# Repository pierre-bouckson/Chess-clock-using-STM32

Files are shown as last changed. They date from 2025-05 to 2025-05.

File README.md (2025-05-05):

# Chess Clock using STM32

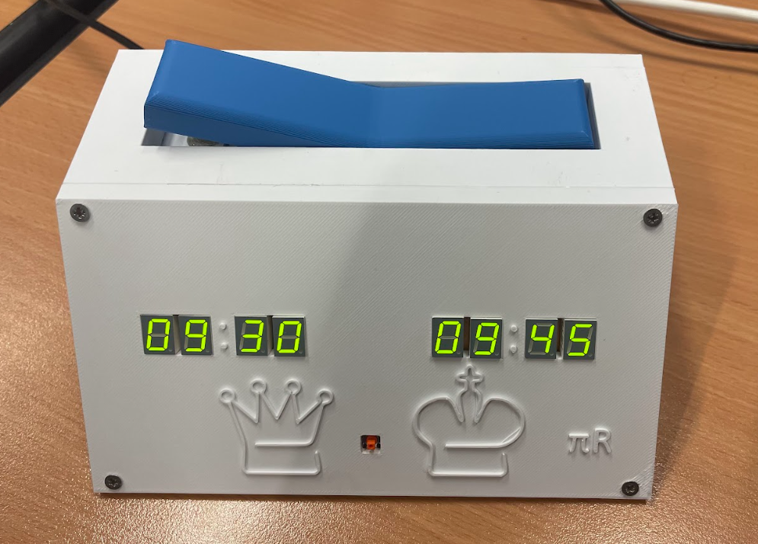
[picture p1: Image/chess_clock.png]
Chess Clock Overview


A fully functional chess clock built with an STM32 microcontroller, using hardware timers and external components for a realistic, competitive experience. This project combines embedded programming, electronics, and 3D printing.

---

## Required Equipment

1. **STM32F072RB** microcontroller (or any STM32 with hardware timers)
2. **3D-printed enclosure**
3. **5V power supply** (via USB power bank)
4. **4 screws** (for enclosure assembly)
5. **Shaft** – 3.5mm diameter, 6cm long
6. **4 magnets**
7. **8-digit 7-segment display**  
   [TDSG3160-M – Vishay](https://fr.farnell.com/vishay/tdsg3160-m/7-seg-display-com-cathode-grn/dp/3777869)
8. **2 LED display drivers**  
   [MAX6958AAEE – Analog Devices](https://fr.farnell.com/analog-devices/max6958aaee/driver-afficheur-led-40-a-125/dp/2516031)
9. **Passive components**: resistors, capacitors, tactile button, etc.

---

## Tools Used

- [KiCad](https://kicad.org/) – for PCB design
- [STM32CubeIDE](https://www.st.com/en/development-tools/stm32cubeide.html) – for firmware development

---

## Project Overview

The chess clock is powered by an **STM32F072RB**, using two hardware timers (TIM6 and TIM7) to track each player's countdown in real time. Turn switching is handled by a physical mechanism using a rotating shaft and magnets. Two **MAX6958** drivers control the 7-segment displays. The clock supports multiple time modes and optional time increments.

---

## Assembly Guide

### 1. Print the Enclosure

- Insert magnets into the 4 dedicated holes.
- Create a custom push-button using aluminum (as shown below):

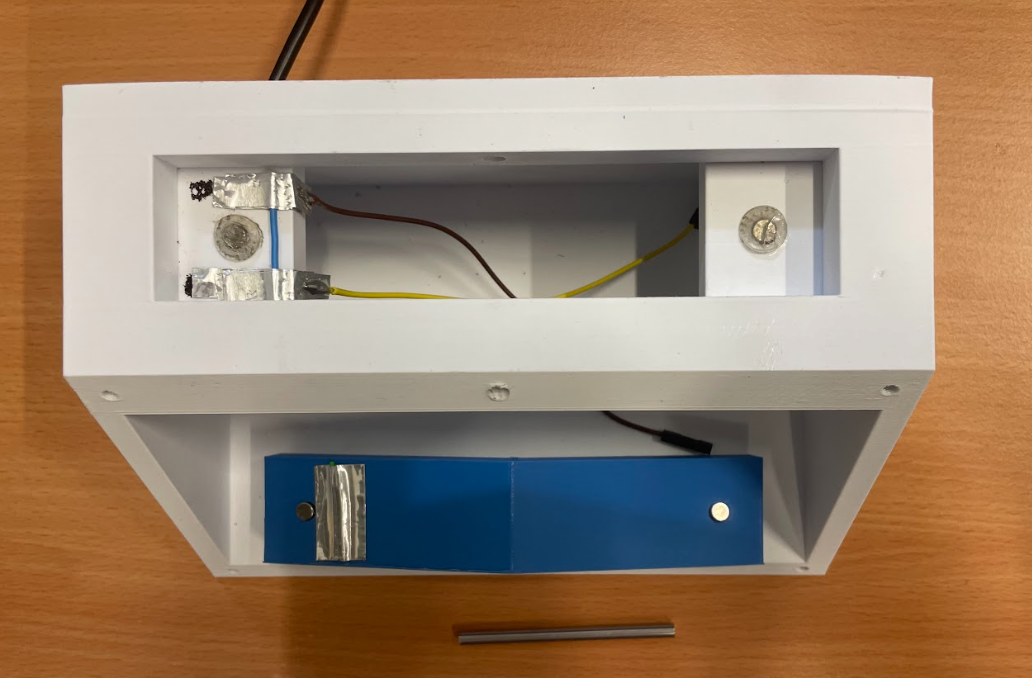
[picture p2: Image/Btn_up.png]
Button Example
  

- Connect the button between **5V** and **PB0**.
- Drill a hole in the enclosure to pass the power cable.

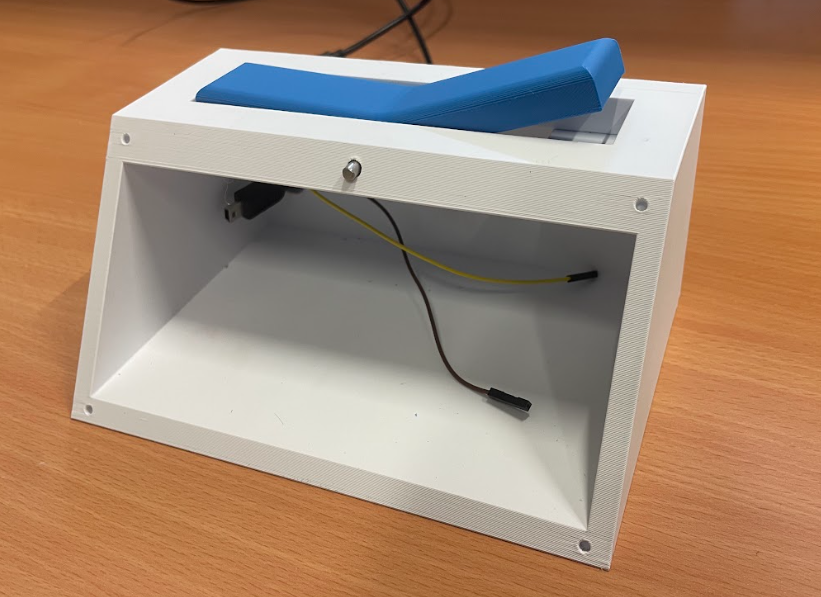
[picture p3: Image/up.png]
Wiring Example
  

### 2. Prepare the Electronics

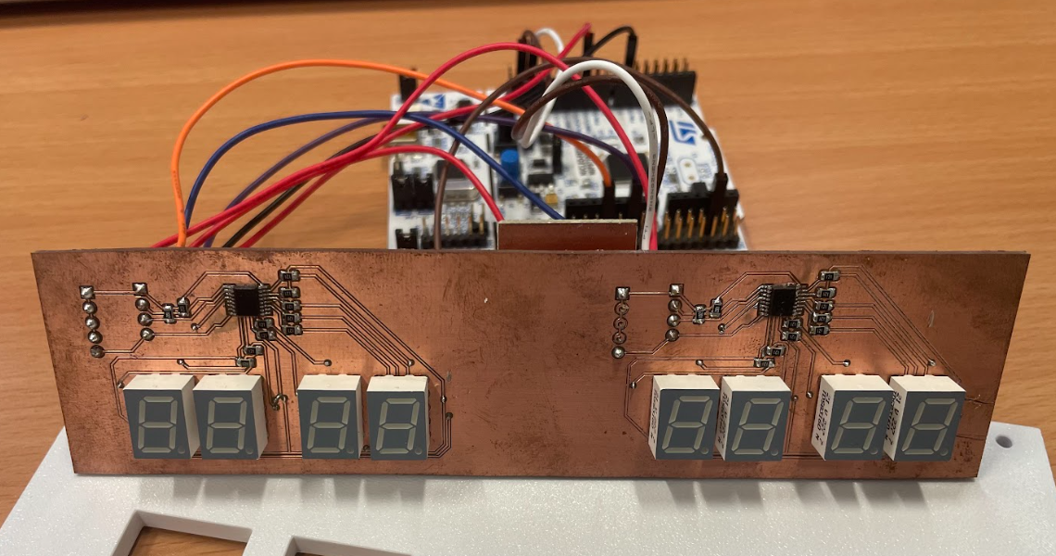
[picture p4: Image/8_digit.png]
Display Wiring
  

- Use **4 pull-up resistors** (1kΩ) for I2C communication.
- Use **9 resistors** (330Ω) for the LED segments.
- Connect the first display driver to:  
  - 3.3V, GND  
  - PB8 (SCL), PB9 (SDA)

- Connect the second driver to:  
  - 3.3V, GND  
  - PB10 (SCL), PB11 (SDA)

> Don't forget to add **decoupling capacitors** near the power pins.

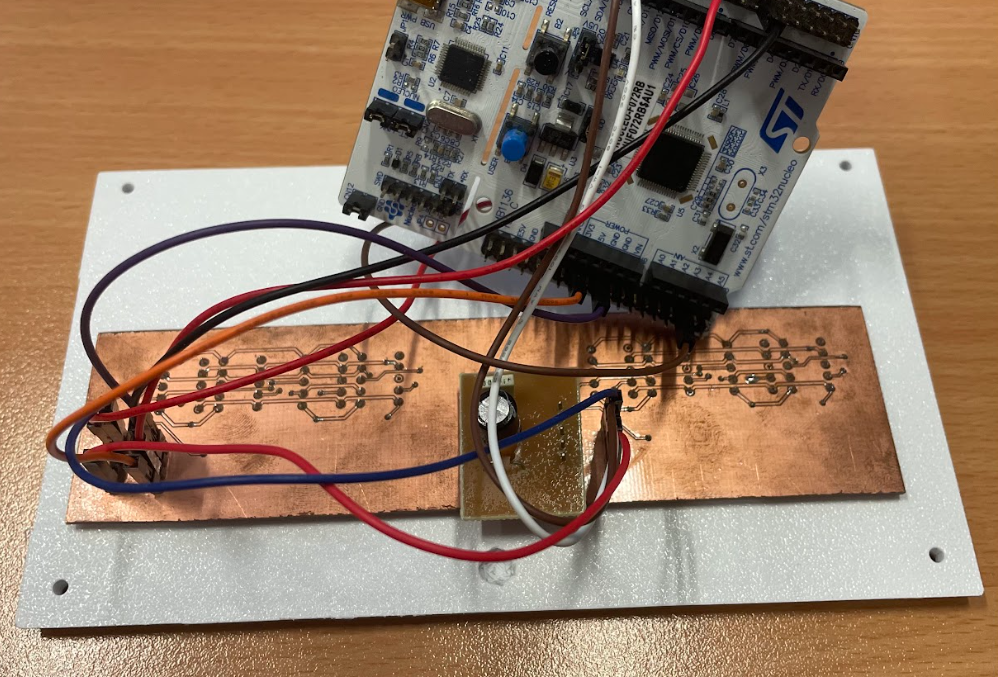
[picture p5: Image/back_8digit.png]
Back View
  

---

## Repository Structure

- `3D_model/` – 3D-printable enclosure files (STL)
- `software_STM32/` – STM32 firmware (C)
- `Image/` – Photos
- `hardware_kicad/` – Schematics and PCB files
- `README.md` – This file

---

Feel free to clone the repository, give feedback, or open issues!

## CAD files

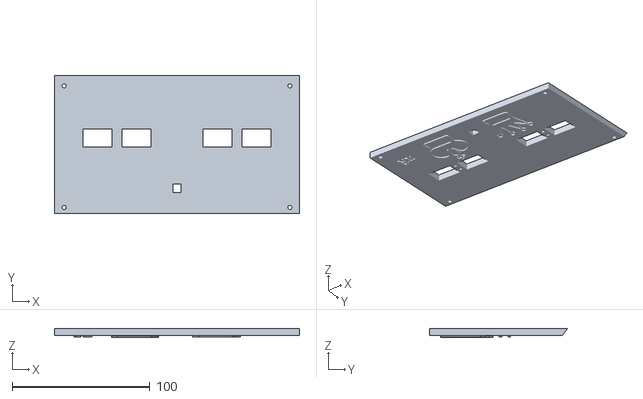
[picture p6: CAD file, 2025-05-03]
3D_model/STL/Assemblagev4-fin.STL
177.6 x 100.0 x 6.18

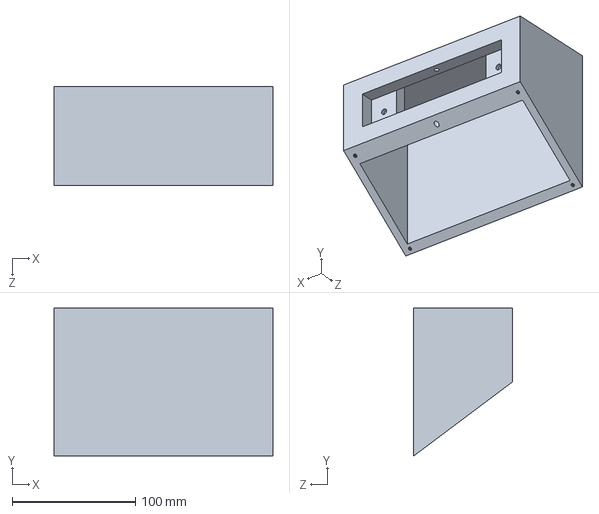
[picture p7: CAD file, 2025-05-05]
3D_model/SolidWorks/boite.SLDPRT
177.6 x 120.0 x 80.0 mm

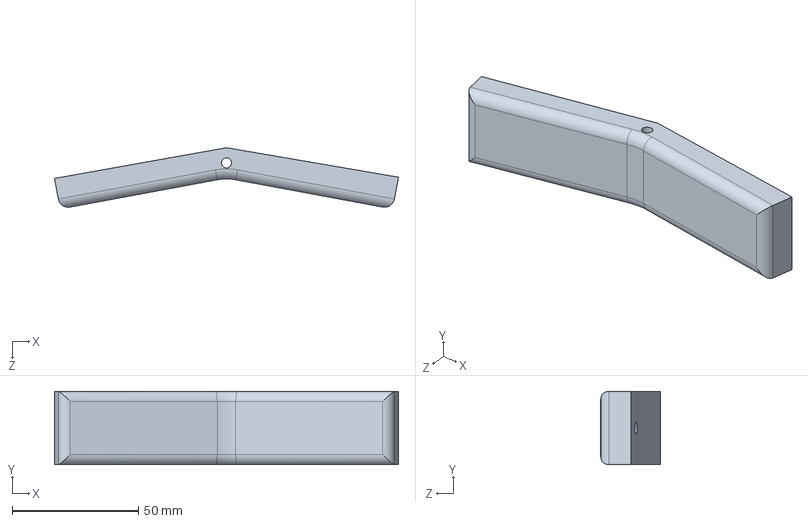
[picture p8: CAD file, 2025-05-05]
3D_model/SolidWorks/bouton.SLDPRT
136.1 x 29.0 x 23.5 mm

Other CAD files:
3D_model/STL/boite_2.0.STL
3D_model/SolidWorks/face.SLDPRT
3D_model/STL/bouton2.0.STL
3D_model/STL/bouton.STL

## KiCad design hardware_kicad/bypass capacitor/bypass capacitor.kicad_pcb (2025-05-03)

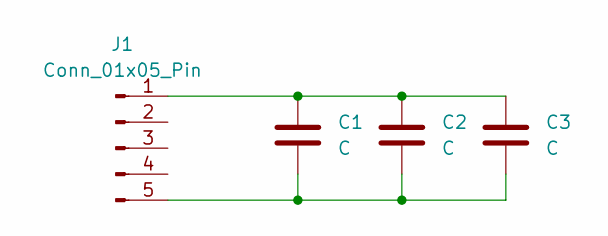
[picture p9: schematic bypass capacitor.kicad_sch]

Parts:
C1: C; C_Disc_D5.1mm_W3.2mm_P5.00mm
C2: C; C_Rect_L9.0mm_W2.5mm_P7.50mm_MKT
C3: C; CP_Radial_D8.0mm_P3.50mm
J1: Conn_01x05_Pin; PinHeader_1x05_P2.54mm_Vertical

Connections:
unnamed: C1.1, C2.1, C3.1, J1.1
unnamed: C1.2, C2.2, C3.2, J1.5

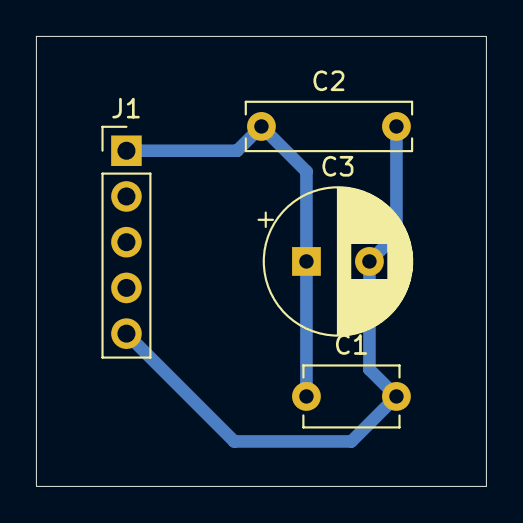
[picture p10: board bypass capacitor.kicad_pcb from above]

Board: 2 copper layers, 25.0 x 25.0 mm, 4 parts (0 on the bottom side), 2 nets.

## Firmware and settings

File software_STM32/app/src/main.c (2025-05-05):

/*
 * main.c
 *
 *  Created on: 5 août 2017
 *      Author: Pierre
 */


 #include "stm32f0xx.h"
 #include "bsp.h"
 #include "delay.h"
 #include "main.h"
 #include "sinewave_table.h"
 #include "rtc.h"
 
 #define N 60000
 
 // Static functions
 static void SystemClock_Config(void);
 void temps_bonus(uint8_t joueur);
 
 
 uint16_t	TIM6_counter;
 uint16_t	TIM7_counter;
 
 uint8_t min_passe_TIM6 = 0;
 uint8_t min_passe_TIM7 = 0;
 
 uint8_t min_TIM6;
 uint8_t min_TIM7;
 
 uint8_t etat = 1;
 uint8_t etat_btn;
 uint8_t temps = 1;
 uint8_t button_irq = 0;
 uint8_t button_irqPA4;
 uint8_t button_irqPC3;
 uint8_t choose = 1;
 
 uint32_t temps_bonus1 = 0;
 uint32_t temps_bonus2 = 0;
 
 
 uint32_t    Temps_a_jouer; //   <-----------  Temps des joueurs
 
 
 // Main function
 int main()
 {
	 // Configure System Clock
	 SystemClock_Config();
 
	 BSP_PB_Init();
	 BSP_PBPA4_Init();
 
	 BSP_TIMER6_Timebase_Init();  //Timer6
	 BSP_TIMER7_Timebase_Init();  //Timer7
 
	 BSP_I2C1_Init1();
	 BSP_I2C1_Init2();
 
	 MAX6958_Init1();  //Driver LED 1
	 MAX6958_Init2();  //Driver LED 2
 
	 BSP_NVIC_Init();
 
	 // Main loop
	 while(1)
	 {
 
		 if (button_irq >= 1)
		 {
			 if(temps == 5)
			 {
				 temps=1;
			 }
			 else
			 {
				 temps++;
			 }
 
			 TIM6->EGR |= TIM_EGR_UG;
			 TIM7->EGR |= TIM_EGR_UG;
			 TIM6->CR1 &= ~TIM_CR1_CEN;
			 TIM7->CR1 &= ~TIM_CR1_CEN;
 
			 etat = 1;
			 choose = 1;
 
			 min_passe_TIM6 = 0;
			 min_passe_TIM7 = 0;
			 min_TIM6 = 0;
			 min_TIM7 = 0;
			 temps_bonus1=0;
			 temps_bonus2=0;
 
			 MAX6958_Init1();
			 MAX6958_Init2();
 
			 button_irq = 0;
 
			 etat_btn = BSP_PBPA4_GetState();
		 }
 
 
		 switch(temps)
		 {
		 case 1:
			 Temps_a_jouer = 60000;
			 break;
		 case 2 :
			 Temps_a_jouer = 180000;
			 break;
		 case 3 :
			 Temps_a_jouer = 180000;
			 break;
		 case 4 :
			 Temps_a_jouer = 300000;
			 break;
		 case 5 :
			 Temps_a_jouer = 600000;
			 break;
		 }
 
 
		 switch(etat)
		 {
		 case 1 :  //		Etat de debut, aucune clock lancer
			 if(BSP_PBPA4_GetState() != etat_btn){
				 choose = 0;
				 if(BSP_PBPA4_GetState() == 0)
				 {
					 etat = 3;
				 }
				 if(BSP_PBPA4_GetState() == 1)
				 {
					 etat = 2;
				 }
			 }
			 break;
 
		 case 2 :
 
			 TIM6->CR1 &= ~TIM_CR1_CEN;//		Pause TIM6
			 TIM7->CR1 |= TIM_CR1_CEN;//         TIM7 lancer
			 if(BSP_PBPA4_GetState() == 0)
			 {
				 etat = 3;
				 temps_bonus(1);
			 }
			 break;
 
		 case 3 :
 
			 TIM7->CR1 &= ~TIM_CR1_CEN;// 		Pause TIM7
			 TIM6->CR1 |= TIM_CR1_CEN;//         TIM6 lancer
			 if(BSP_PBPA4_GetState() == 1)
			 {
				 etat = 2;
				 temps_bonus(2);
			 }
			 break;
		 }
 
		 // PRINT DIGIT
		 if(choose == 0)
		 {
			 print_digit1(Temps_a_jouer + temps_bonus1 - (min_passe_TIM7*60000) - TIM7->CNT);
			 print_digit2(Temps_a_jouer + temps_bonus2 - (min_passe_TIM6*60000) - TIM6->CNT);
		 }
		 else
		 {
			 print_digit2(Temps_a_jouer);
			 if(temps == 3)
			 {
				 print_digit1(2000);
			 }
			 else if(temps == 1)
			 {
				 print_digit1(1000);
			 }
			 else
			 {
				 print_digit1(0);
			 }
 
		 }
 
		 // AJOUT MIN
		 if(min_TIM6 == 1)
		 {
			 min_passe_TIM6++;
			 min_TIM6 = 0;
		 }
 
		 if(min_TIM7 == 1)
		 {
			 min_passe_TIM7++;
			 min_TIM7 = 0;
		 }
 
		 // SI PERDU :
		 if((Temps_a_jouer + temps_bonus1 - (min_passe_TIM6*60000) - TIM6->CNT) < 500){
			 etat = 1;				//retourne a l'etat 1
			 print_digit2(0);		//Rester a 00:00 si perdu au temps
		 }
 
		 if((Temps_a_jouer + temps_bonus2 - (min_passe_TIM7*60000) - TIM7->CNT) < 500){
			 etat = 1;
			 print_digit1(0);		//Rester a 00:00 si perdu au temps
		 }
 
	 }
 
 }
 
 void temps_bonus(uint8_t joueur)
 {
	 if(temps == 3)
	 {
		 if(joueur == 1)
		 {
			 temps_bonus1 += 2000;
		 }
		 else
		 {
			 temps_bonus2 += 2000;
		 }
	 }
	 if(temps == 1)
	 {
		 if(joueur == 1)
		 {
			 temps_bonus1 += 1000;
		 }
		 else
		 {
			 temps_bonus2 += 1000;
		 }
	 }
 }
 
 
 
 
 
 static void SystemClock_Config()
 {
	 uint32_t	HSE_Status;
	 uint32_t	PLL_Status;
	 uint32_t	SW_Status;
	 uint32_t	timeout = 0;
	 timeout = 1000000;
	 // Start HSE in Bypass Mode
	 RCC->CR |= RCC_CR_HSEBYP;
	 RCC->CR |= RCC_CR_HSEON;
	 // Wait until HSE is ready
	 do
	 {
		 HSE_Status = RCC->CR & RCC_CR_HSERDY_Msk;
		 timeout--;
	 } while ((HSE_Status == 0) && (timeout > 0));
	 // Select HSE as PLL input source
	 RCC->CFGR &= ~RCC_CFGR_PLLSRC_Msk;
	 RCC->CFGR |= (0x02 <<RCC_CFGR_PLLSRC_Pos);
	 // Set PLL PREDIV to /1
	 RCC->CFGR2 = 0x00000000;
	 // Set PLL MUL to x6
	 RCC->CFGR &= ~RCC_CFGR_PLLMUL_Msk;
	 RCC->CFGR |= (0x04 <<RCC_CFGR_PLLMUL_Pos);
	 // Enable the main PLL
	 RCC-> CR |= RCC_CR_PLLON;
	 // Wait until PLL is ready
	 do
	 {
		 PLL_Status = RCC->CR & RCC_CR_PLLRDY_Msk;
		 timeout--;
	 } while ((PLL_Status == 0) && (timeout > 0));
	 // Set AHB prescaler to /1
	 RCC->CFGR &= ~RCC_CFGR_HPRE_Msk;
	 RCC->CFGR |= RCC_CFGR_HPRE_DIV1;
	 //Set APB1 prescaler to /1
	 RCC->CFGR &= ~RCC_CFGR_PPRE_Msk;
	 RCC->CFGR |= RCC_CFGR_PPRE_DIV1;
	 // Enable FLASH Prefetch Buffer and set Flash Latency
	 FLASH->ACR = FLASH_ACR_PRFTBE | FLASH_ACR_LATENCY;
	 /* --- Until this point, MCU was still clocked by HSI at 8MHz ---*/
	 /* --- Switching to PLL at 48MHz Now!  Fasten your seat belt! ---*/
	 // Select the main PLL as system clock source
	 RCC->CFGR &= ~RCC_CFGR_SW;
	 RCC->CFGR |= RCC_CFGR_SW_PLL;
	 // Wait until PLL becomes main switch input
	 do
	 {
		 SW_Status = (RCC->CFGR & RCC_CFGR_SWS_Msk);
		 timeout--;
	 } while ((SW_Status != RCC_CFGR_SWS_PLL) && (timeout > 0));
	 /* --- Here we go! ---*/
	 /*--- Use PA8 as MCO output at 48/16 = 3MHz ---*/
	 // Set MCO source as SYSCLK (48MHz)
	 RCC->CFGR &= ~RCC_CFGR_MCO_Msk;
	 RCC->CFGR |=  RCC_CFGR_MCOSEL_SYSCLK;
	 // Set MCO prescaler to /16 -> 3MHz
	 RCC->CFGR &= ~RCC_CFGR_MCOPRE_Msk;
	 RCC->CFGR |=  RCC_CFGR_MCOPRE_DIV16;
	 // Enable GPIOA clock
	 RCC->AHBENR |= RCC_AHBENR_GPIOAEN;
	 // Configure PA8 as Alternate function
	 GPIOA->MODER &= ~GPIO_MODER_MODER8_Msk;
	 GPIOA->MODER |= (0x02 <<GPIO_MODER_MODER8_Pos);
	 // Set to AF0 (MCO output)
	 GPIOA->AFR[1] &= ~(0x0000000F);
	 GPIOA->AFR[1] |=  (0x00000000);
	 // Update SystemCoreClock global variable
	 SystemCoreClockUpdate();
 }
 

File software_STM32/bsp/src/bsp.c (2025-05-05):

/*
 * bsp.c
 *
 *  Created on: 5 août 2017
 *      Author: Laurent
 */

 #include "bsp.h"

 /*
  * BSP_PB_Init()
  * Initialize Push-Button pin (PC13) as input without Pull-up/Pull-down
  */
 
 void BSP_PB_Init()
 {
	 // Enable GPIOB clock
	 RCC->AHBENR |= RCC_AHBENR_GPIOBEN;
 
	 // Configure PB0 as input
	 GPIOB->MODER &= ~GPIO_MODER_MODER0_Msk;
	 GPIOB->MODER |= (0x00 <<GPIO_MODER_MODER0_Pos);
 
	 // Enable PB0 Pull-down
	 GPIOB->PUPDR &= ~GPIO_PUPDR_PUPDR0_Msk;
	 GPIOB->PUPDR |= (0x2UL << GPIO_PUPDR_PUPDR0_Pos);
 
	 // Enable SYSCFG clock
	 RCC->APB2ENR |= RCC_APB2ENR_SYSCFGEN;
 
	 // Select Port C as interrupt source for EXTI line 13
	 SYSCFG->EXTICR[0] &= ~ SYSCFG_EXTICR1_EXTI0_Msk;
	 SYSCFG->EXTICR[0] |=   SYSCFG_EXTICR1_EXTI0_PB;
 
	 // Enable EXTI line 0
	 EXTI->IMR |= EXTI_IMR_IM0;
 
	 // Disable Rising / Enable Falling trigger
	 EXTI->RTSR &= ~EXTI_RTSR_RT0;
	 EXTI->FTSR |=  EXTI_FTSR_FT0;
 }
 /*
  * BSP_PB_GetState()
  * Returns the state of the button (0=released, 1=pressed)
  */
 
 void BSP_PBPA4_Init()
 {
	 // Enable GPIOA clock
	 RCC->AHBENR |= RCC_AHBENR_GPIOAEN;
 
	 // Configure PA4 as input
	 GPIOA->MODER &= ~GPIO_MODER_MODER4_Msk;
	 GPIOA->MODER |= (0x00 <<GPIO_MODER_MODER4_Pos);
 
	 // Enable PA4 Pull-down
	 GPIOA->PUPDR &= ~GPIO_PUPDR_PUPDR4_Msk;
	 GPIOA->PUPDR |= (0x2UL << GPIO_PUPDR_PUPDR4_Pos);
 
	 // Enable SYSCFG clock
	 RCC->APB2ENR |= RCC_APB2ENR_SYSCFGEN;
 
	 // Select Port C as interrupt source for EXTI line 13
	 SYSCFG->EXTICR[1] &= ~ SYSCFG_EXTICR2_EXTI4_Msk;
	 SYSCFG->EXTICR[1] |=   SYSCFG_EXTICR2_EXTI4_PA;
 
	 // Enable EXTI line 4
	 EXTI->IMR |= EXTI_IMR_IM4;
 
	 // Disable Rising / Enable Falling trigger
	 EXTI->RTSR &= ~EXTI_RTSR_RT4;
	 EXTI->FTSR |=  EXTI_FTSR_FT4;
 
 }
 
 
 uint8_t BSP_PB_GetState()
 {
	 uint8_t state;
	 if ((GPIOB->IDR & GPIO_IDR_0) == GPIO_IDR_0)
	 {
		 state = 1;
	 }
	 else
	 {
		 state = 0;
	 }
	 return state;
 }
 
 uint8_t BSP_PBPA4_GetState()
 {
	 uint8_t state;
	 if ((GPIOA->IDR & GPIO_IDR_4) == GPIO_IDR_4)
	 {
		 state = 1;
	 }
	 else
	 {
		 state = 0;
	 }
	 return state;
 }
 
 uint8_t BSP_PBPA4_Toggle()
 {
	 uint8_t etat = 0;
	 if(BSP_PBPA4_GetState() == 1)
	 {
 
	 }
 }
 
 
 /*
  * BSP_TIMER_Timebase_Init()
  * TIM6 at 48MHz
  * Prescaler   = 48000  -> Counting frequency is 1kHz
  * Auto-reload = 10 	-> Update period is 10ms
  * Enable Update Interrupt
  */
 extern uint16_t    Temps_a_jouer;
 void BSP_TIMER6_Timebase_Init()
 {
	 // Enable TIM6 clock
	 RCC->APB1ENR |= RCC_APB1ENR_TIM6EN;
 
	 // Reset TIM6 configuration
	 TIM6->CR1 = 0x0000;
	 TIM6->CR2 = 0x0000;
 
	 // Set TIM6 prescaler
	 // Fck = 48MHz -> /48000 = 1KHz counting frequency
	 TIM6->PSC = (uint16_t) 48000 -1;
 
	 // Set TIM6 auto-reload register for 60s
	 TIM6->ARR = (uint16_t) 60000 -1;
 
	 //Enable STOP
	 TIM6->CR1 |= (0x1UL << (3U));
 
	 // Enable auto-reload preload
	 TIM6->CR1 |= TIM_CR1_ARPE;
 
	 //Enable Interrupt
	 TIM6->DIER = (0x1UL << (0U));
 
	 TIM6->CR1 &= ~TIM_CR1_CEN;
 
	 //Enable TIM6
	 //TIM6->CR1 |= TIM_CR1_CEN;
 }
 
 void BSP_TIMER7_Timebase_Init()
 {
	 // Enable TIM6 clock
	 RCC->APB1ENR |= RCC_APB1ENR_TIM7EN;
 
	 // Reset TIM6 configuration
	 TIM7->CR1 = 0x0000;
	 TIM7->CR2 = 0x0000;
 
	 // Set TIM6 prescaler
	 // Fck = 48MHz -> /48000 = 1KHz counting frequency
	 TIM7->PSC = (uint16_t) 48000 -1;
 
	 // Set TIM6 auto-reload register for 60s
	 TIM7->ARR = (uint16_t) 60000 -1;
 
	 //Enable STOP
	 TIM7->CR1 |= (0x1UL << (3U));
 
	 // Enable auto-reload preload
	 TIM7->CR1 |= TIM_CR1_ARPE;
 
	 //Enable Interrupt
	 TIM7->DIER = (0x1UL << (0U));
 
	 TIM7->CR1 &= ~TIM_CR1_CEN;
 
	 //Enable TIM6
	 //TIM7->CR1 |= TIM_CR1_CEN;
 }
 
 void BSP_NVIC_Init()
 {
	 // Set maximum priority for EXTI line 4 to 15 interrupts
	 NVIC_SetPriority(EXTI0_1_IRQn, 2);
 
	 // Enable EXTI line 4 to 15 (user button on line 13) interrupts
	 NVIC_EnableIRQ(EXTI0_1_IRQn);
 
 //	// Set maximum priority for EXTI line 4 to 15 interrupts
 //	NVIC_SetPriority(EXTI4_15_IRQn, 2);
 //
 //	// Enable EXTI line 4 to 15 (user button on line 13) interrupts
 //	NVIC_EnableIRQ(EXTI4_15_IRQn);
 //
 //	// Set maximum priority for EXTI line 4 to 15 interrupts
 //	NVIC_SetPriority(EXTI2_3_IRQn, 3);
 //
 //	// Enable EXTI line 4 to 15 (user button on line 13) interrupts
 //	NVIC_EnableIRQ(EXTI2_3_IRQn);
 
	 // Interrupt TIM6
	 NVIC_SetPriority(TIM6_DAC_IRQn, 0);
 
	 // Enable
	 NVIC_EnableIRQ(TIM6_DAC_IRQn);
 
	 // TIM7
	 NVIC_SetPriority(TIM7_IRQn, 1);
 
	 // Enable
	 NVIC_EnableIRQ(TIM7_IRQn);
 }
 
 
 void BSP_I2C1_Init1()
 {
	 // Pin configuration for I2C2 pins
	 // SCL -> PB8
	 // SDA -> PB9
	 // Enable GPIOB clock
	 RCC->AHBENR |= RCC_AHBENR_GPIOBEN;
 
	 // Configure PB8, PB9 as AF mode
	 GPIOB->MODER &= ~(GPIO_MODER_MODER8 | GPIO_MODER_MODER9);
	 GPIOB->MODER |= (0x02 <<16U) | (0x02 <<18U);
 
	 // Connect to I2C1 (AF1)
	 GPIOB->AFR[1] &= ~(0x000000FF);
	 GPIOB->AFR[1] |=   0x00000011;
 
	 // Setup Open-Drain
	 GPIOB->OTYPER |= GPIO_OTYPER_OT_8 | GPIO_OTYPER_OT_9;
 
	 // Select SYSCLK as I2C1 clock (48MHz)
	 RCC->CFGR3 |= RCC_CFGR3_I2C1SW;
 
	 // Enable I2C1 clock
	 RCC->APB1ENR |= RCC_APB1ENR_I2C1EN;
 
	 // Make sure I2C1 is disabled
	 I2C1->CR1 &= ~I2C_CR1_PE;
 
	 // Reset I2C1 Configuration to default values
	 I2C1->CR1 	  = 0x00000000;
	 I2C1->CR2 	  = 0x00000000;
	 I2C1->TIMINGR = 0x00000000;
 
	 // Configure timing for 100kHz, 50% duty cycle
	 I2C1->TIMINGR |= ((4 -1) <<I2C_TIMINGR_PRESC_Pos); // Clock prescaler /4 -> 12MHz
	 I2C1->TIMINGR |= (120 	 <<I2C_TIMINGR_SCLH_Pos);  // High half-period = 5µs
	 I2C1->TIMINGR |= (120     <<I2C_TIMINGR_SCLL_Pos);  // Low  half-period = 5µs
 
	 // Enable I2C1
	 I2C1->CR1 |= I2C_CR1_PE;
 }
 
 
 uint8_t	BSP_I2C1_Write1( uint8_t device_address,
		 uint8_t register_address,
		 uint8_t *buffer, uint8_t nbytes )
 {
	 uint32_t 	timeout;	// Flag waiting timeout
	 uint8_t		n;			// Loop counter
 
	 // Set device address
	 I2C1->CR2 &= ~I2C_CR2_SADD_Msk;
	 I2C1->CR2 |= ((device_address <<1U) <<I2C_CR2_SADD_Pos);
 
	 // Set I2C in Write mode
	 I2C1->CR2 &= ~I2C_CR2_RD_WRN;
 
	 // Transfer NBYTES, with AUTOEND
	 I2C1->CR2 &= ~I2C_CR2_NBYTES;
	 I2C1->CR2 |= ((nbytes+1) <<16U);
	 I2C1->CR2 |= I2C_CR2_AUTOEND;
 
	 // Clear STOPF flag
	 I2C1->ICR |= I2C_ICR_STOPCF;
 
	 // Start I2C transaction
	 I2C1->CR2 |= I2C_CR2_START;
 
	 // Wait for TXIS with timeout
	 timeout = 100000;
	 while (((I2C1->ISR) & I2C_ISR_TXIS) != I2C_ISR_TXIS)
	 {
		 timeout--;
		 if (timeout == 0) return 1;
	 }
 
	 // Send register address
	 I2C1->TXDR = register_address;
 
	 n = nbytes;
	 while(n>0)
	 {
		 // Wait for TXIS with timeout
		 timeout = 100000;
		 while (((I2C1->ISR) & I2C_ISR_TXIS) != I2C_ISR_TXIS)
		 {
			 timeout--;
			 if (timeout == 0) return 2;
		 }
 
		 // Send data
		 I2C1->TXDR = *buffer;
		 buffer++;
		 n--;
	 }
 
	 // Wait for STOPF with timeout
	 timeout = 100000;
	 while (((I2C1->ISR) & I2C_ISR_STOPF) != I2C_ISR_STOPF)
	 {
		 timeout--;
		 if (timeout == 0) return 3;
	 }
 
	 // Return success
	 return 0;
 }
 
 void BSP_I2C1_Init2()
 {
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
